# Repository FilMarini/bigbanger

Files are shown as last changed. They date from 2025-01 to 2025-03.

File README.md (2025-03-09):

# BigBanger :boom:

<p align="center">
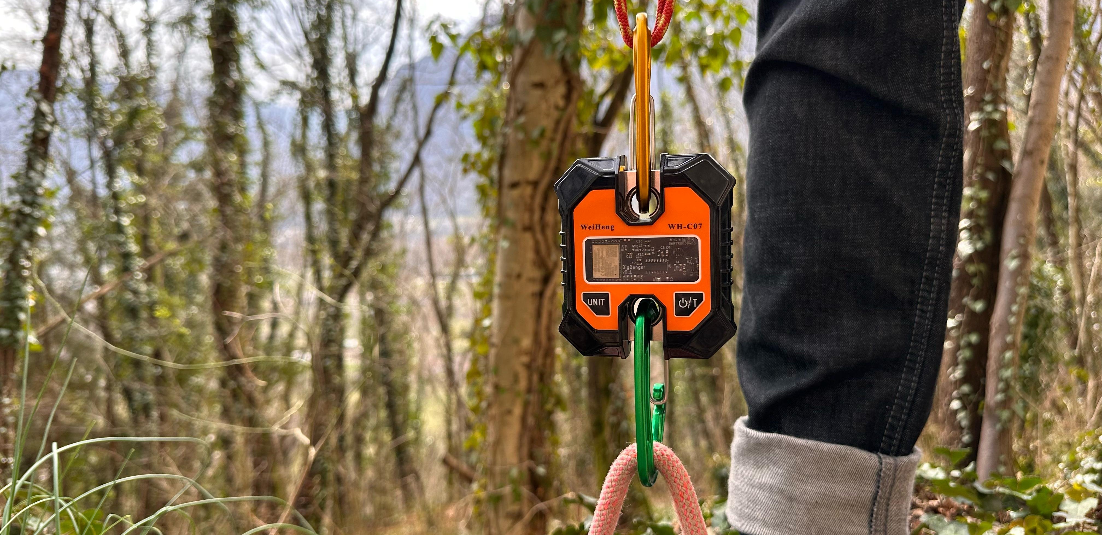
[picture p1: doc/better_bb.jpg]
BigBanger v1.0
  
</p>

BigBanger is an ESP32-based open-source project that combines firmware and hardware to create a Bluetooth-enabled scale, mainly designed for climbing training.

This scale is fully compatible with the [Tindeq Progressor API](https://tindeq.com/progressor_api/), enabling easy integration with apps that support them, including the official Tindeq Progressor app.

The BigBanger board is designed to exploit the housing of cheap scales that you can buy on Amazon/Aliexpress.

Currently, the supported housing are:

* [WeiHeng WH-C07](https://it.aliexpress.com/item/1005004488455473.html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)
* [WeiHeng WH-C100](https://it.aliexpress.com/item/1005007661854154.html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)

This is not the first open-source Tindeq Progressor-like project. The [hangman](https://github.com/kesyog/hangman) is a very similar example. BigBanger was developed from scratch as a personal learning experience.

## Repository structure

* **firmware**: contains the micropython firmware for the ESP32

* **hardware**: contains the Kicad project for the PCB

## Prerequisite

* Python 3.7 or newer

* [esptool](https://docs.espressif.com/projects/esptool/en/latest/esp32/index.html)

* [rshell](https://github.com/dhylands/rshell)

## How-to

1. Build the PCB from the Kicad project. Design is fully compliant with [JLCPCB rules](https://jlcpcb.com/capabilities/pcb-capabilities)

    * The JLCPCB gerbers and assembly files are available in the [release page](https://github.com/FilMarini/bigbanger/releases/tag/v1.1)

    * If you assemble the PCB with JLCPCB, go to step 3

2. Buy the components. [Here](https://www.digikey.it/it/mylists/list/KCSV7UEBPS) is a full Digikey list of parts

3. Get to soldering!

    Battery wiring:
    
    * B+: Red
    * B-: Black

    Load cell wiring:
    
    * E-: Black
    * A-: White
    * A+: Green
    * E+: Red

4. Turn on the BigBanger and connect to PC using the microUSB

    * Device should appear as `/dev/ttyACM*` or `/dev/ttyUSB*`

6. Flash the ESP32 micropython firmware. Instructions and firmware files are [here](https://micropython.org/download/ESP32_GENERIC_C3/)

7. Copy the `.py` files in the 'firmware' folder into the ESP32. Copy the `hx711_gpio.py` file into the ESP32. For this you can use [rshell](https://github.com/dhylands/rshell)

   * Modify the `main.py` file. You need to specify the Bluetooth name for your device (If you want it compatible with the Tindeq Progressor, name must start with `Progressor`) as well as the crane scale used (Supported values are `WH-C07` and `WH-C100`)

    * With [rshell](https://github.com/dhylands/rshell):
    
       ```bash
       git clone --recursive https://github.com/FilMarini/bigbanger.git
       cd bigbanger/firmware
       rshell -p /dev/tty<your device> cp bb_gatt_server.py ble_advertising.py config.py hx711_bb.py utils.py hx711/hx711_gpio.py main.py /pyboard # Probably requires sudo privileges
       ```

9. Start training!

## Calibration

The BigBanger scale comes pre-calibrated, but if for any reason the calibration is lost, you can recalibrate it using the built-in two-point calibration system. This system requires two weight measurements with a 10 kg difference—typically one at zero weight and another at 10 kg.

### How to calibrate

- Turn on the BigBanger scale and ensure it is disconnected from any device.

- Press and hold the Unit button until the LED D5 turns on (this takes a few seconds).

- When the LED turns on, the scale performs the first measurement (normally at zero weight).

- Add 10 kg weight on the scale.

- Press the Unit button again. The LED D5 should turn off.

- The scale is now calibrated and you can now connect to it.

## Acknowledgements

Huge thanks to [Tindeq](https://tindeq.com/product/progressor/) for improving climbing training for all of us with their innovative product and for making their API available to third-party developers, enabling projects like this one. If you find this useful, consider supporting them by getting one of their products—they’re well worth it!

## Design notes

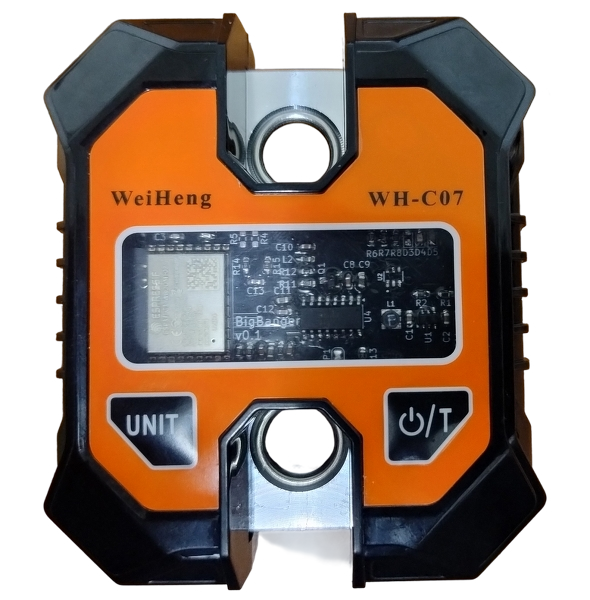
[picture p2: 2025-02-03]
doc/bb.png

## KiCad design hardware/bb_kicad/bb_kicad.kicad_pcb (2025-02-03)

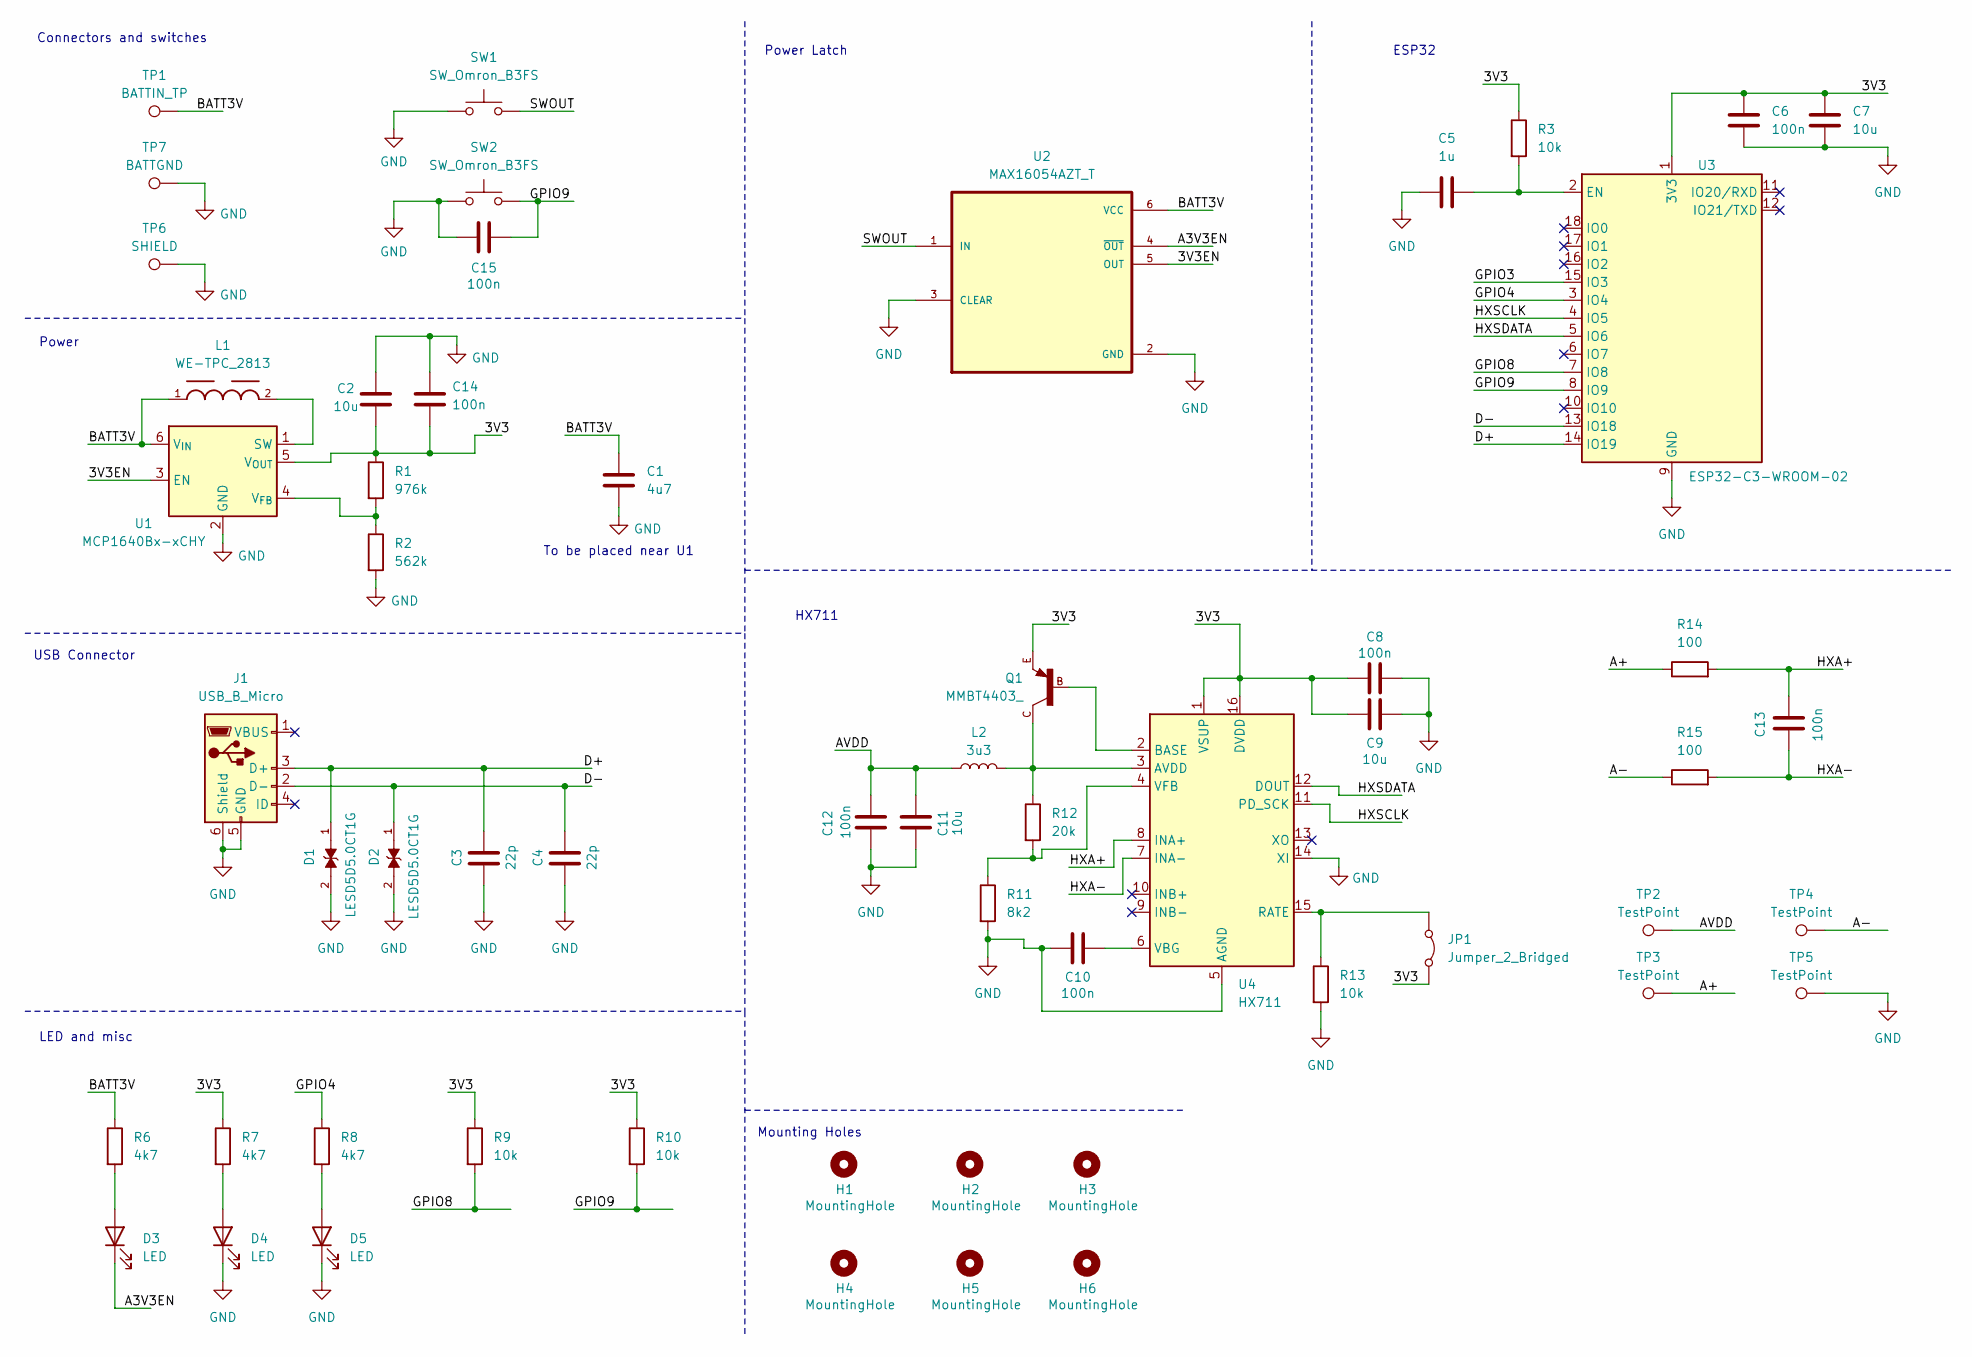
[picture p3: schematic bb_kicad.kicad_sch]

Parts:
C1: 4u7; C_0603_1608Metric_Pad1.08x0.95mm_HandSolder
C2, C7, C9, C11: 10u; C_0603_1608Metric_Pad1.08x0.95mm_HandSolder
C3, C4: 22p; C_0603_1608Metric_Pad1.08x0.95mm_HandSolder
C5: 1u; C_0603_1608Metric_Pad1.08x0.95mm_HandSolder
C6, C8, C10, C12, C13, C14, C15: 100n; C_0603_1608Metric_Pad1.08x0.95mm_HandSolder
D1, D2: LESD5D5.0CT1G; TVS_LESD5D5.0CT1G; PARTREV O
D3, D4, D5: LED; LED_0603_1608Metric_Pad1.05x0.95mm_HandSolder
H1, H2, H3, H4, H5, H6: MountingHole; MountingHole_2.2mm_M2
J1: USB_B_Micro; USB_Micro-B_Amphenol_10118194-0001LF_Horizontal
JP1: Jumper_2_Bridged; SolderJumper-2_P1.3mm_Open_RoundedPad1.0x1.5mm
L1: WE-TPC_2813; DigiKey_Part_Number 732-1089-2-ND
L2: 3u3; L_0603_1608Metric_Pad1.05x0.95mm_HandSolder
Q1: MMBT4403_; SOT23-BEC
R1: 976k; R_0603_1608Metric_Pad0.98x0.95mm_HandSolder
R2: 562k; R_0603_1608Metric_Pad0.98x0.95mm_HandSolder
R3, R9, R10, R13: 10k; R_0603_1608Metric_Pad0.98x0.95mm_HandSolder
R6, R7, R8: 4k7; R_0603_1608Metric_Pad0.98x0.95mm_HandSolder
R11: 8k2; R_0603_1608Metric_Pad0.98x0.95mm_HandSolder
R12: 20k; R_0603_1608Metric_Pad0.98x0.95mm_HandSolder
R14, R15: 100; R_0603_1608Metric_Pad0.98x0.95mm_HandSolder
SW1, SW2: SW_Omron_B3FS; SW_SPST_Omron_B3FS-101xP
TP1: BATTIN_TP; TestPoint_Pad_2.0x2.0mm
TP2, TP3, TP4, TP5: TestPoint; TestPoint_Pad_2.0x2.0mm
TP6: SHIELD; TestPoint_Pad_2.0x2.0mm
TP7: BATTGND; TestPoint_Pad_2.0x2.0mm
U1: MCP1640Bx-xCHY; SOT-23-6
U2: MAX16054AZT_T; SOT95P275X110-6N
U3: ESP32-C3-WROOM-02
U4: HX711; SOP-16_3.9x9.9mm_P1.27mm

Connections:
/3V3: C2.2, C6.2, C7.2, C8.1, C9.1, C14.2, JP1.2 (B), Q1.E, R1.1, R3.1, R7.1, R9.1, R10.1, U1.5 (V_{OUT}), U3.1 (3V3), U4.1 (VSUP), U4.16 (DVDD)
/3V3EN: U1.3 (EN), U2.5 (OUT)
/A3V3EN: D3.1 (K), U2.4 (~OUT)
/A+: R14.1, TP3.1
/A-: R15.1, TP4.1
/AVDD: C11.2, C12.2, L2.1, TP2.1
/BATT3V: C1.1, L1.1, R6.1, TP1.1, U1.6 (V_{IN}), U2.6 (VCC)
/D+: C3.1, D1.1, J1.3 (D+), U3.14 (IO19)
/D-: C4.1, D2.1, J1.2 (D-), U3.13 (IO18)
/GPIO3: U3.15 (IO3)
/GPIO4: R8.1, U3.3 (IO4)
/GPIO8: R9.2, U3.7 (IO8)
/GPIO9: C15.2, R10.2, SW2.2, U3.8 (IO9)
/HXA+: C13.2, R14.2, U4.8 (INA+)
/HXA-: C13.1, R15.2, U4.7 (INA-)
/HXSCLK: U3.4 (IO5), U4.11 (PD_SCK)
/HXSDATA: U3.5 (IO6), U4.12 (DOUT)
/SWOUT: SW1.2, U2.1 (IN)
GND: C1.2, C2.1, C3.2, C4.2, C5.1, C6.1, C7.1, C8.2, C9.2, C10.1, C11.1, C12.1, C14.1, C15.1, D1.2, D2.2, D4.1 (K), D5.1 (K), J1.5 (GND), J1.6 (Shield), R2.2, R11.2, R13.2, SW1.1, SW2.1, TP5.1, TP6.1, TP7.1, U1.2 (GND), U2.2 (GND), U2.3 (CLEAR), U3.9 (GND), U3.19 (GND), U4.5 (AGND), U4.14 (XI)
unnamed: D3.2 (A), R6.2
unnamed: D4.2 (A), R7.2
unnamed: D5.2 (A), R8.2
unnamed: JP1.1 (A), R13.1, U4.15 (RATE)
unnamed: L1.2, U1.1 (SW)
unnamed: R1.2, R2.1, U1.4 (V_{FB})
unnamed: C5.2, R3.2, U3.2 (EN)
unnamed: L2.2, Q1.C, R12.1, U4.3 (AVDD)
unnamed: Q1.B, U4.2 (BASE)
unnamed: C10.2, U4.6 (VBG)
unnamed: R11.1, R12.2, U4.4 (VFB)

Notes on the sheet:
LED and misc
USB Connector
ESP32
Power
Mounting Holes
Connectors and switches
Power Latch
HX711
To be placed near U1

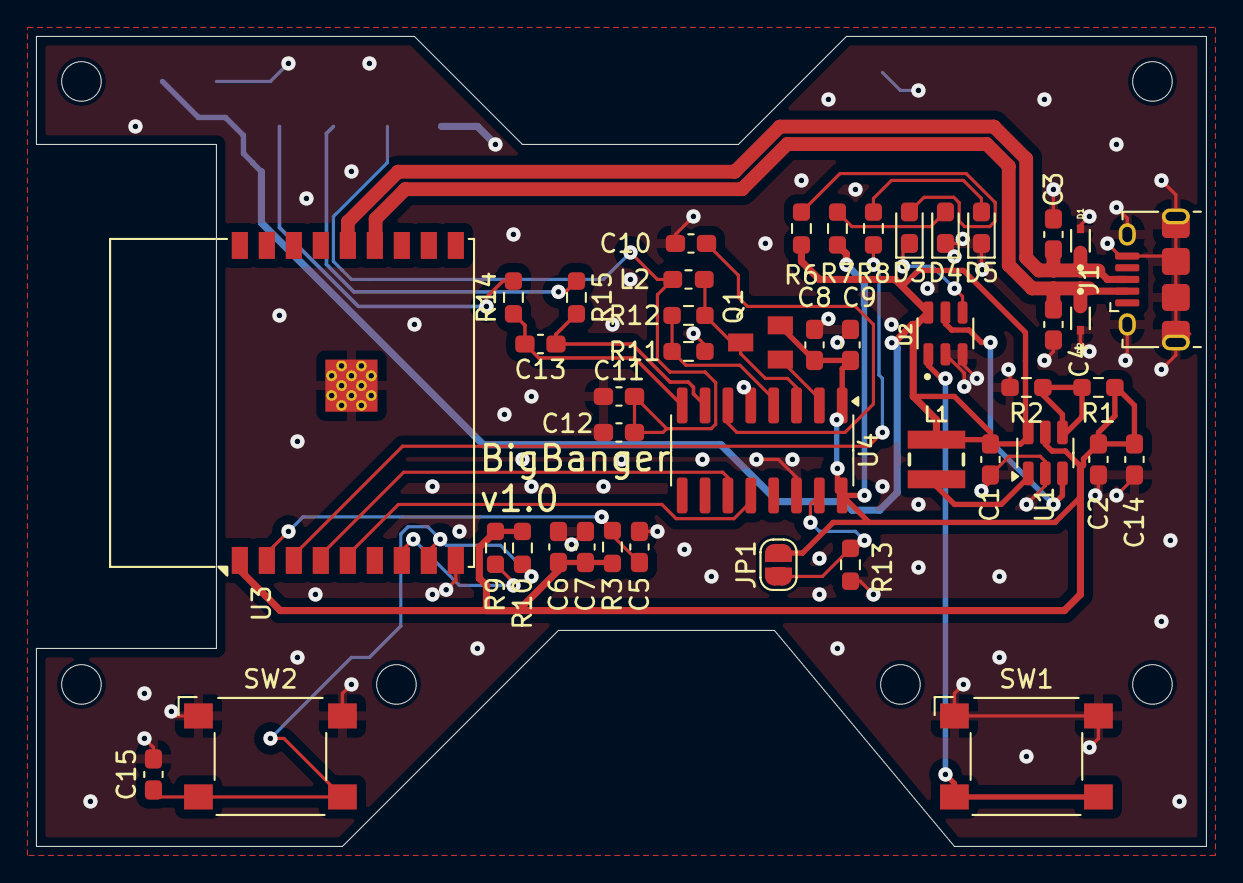
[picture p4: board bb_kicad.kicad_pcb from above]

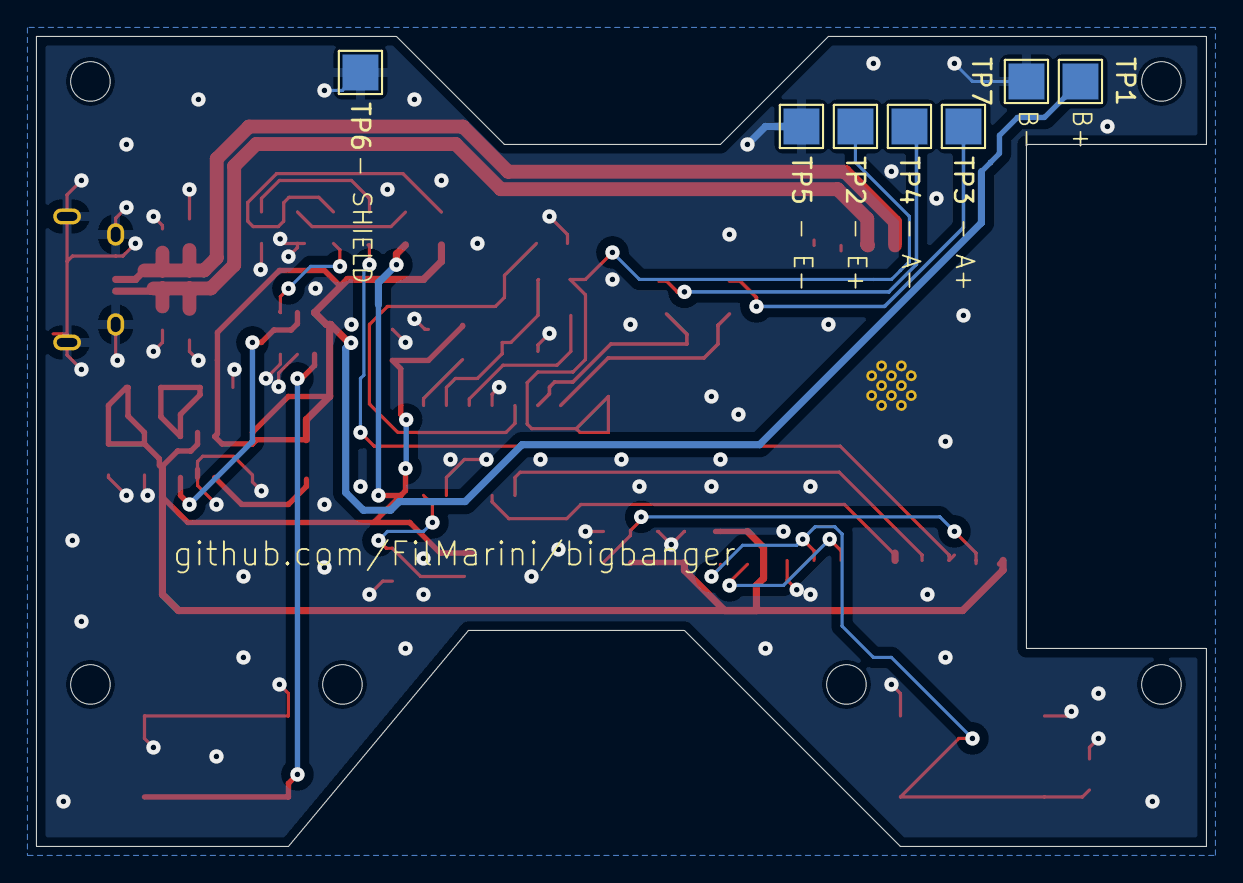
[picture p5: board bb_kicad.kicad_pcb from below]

Board: 2 copper layers, 65.0 x 45.0 mm, 57 parts (7 on the bottom side), 29 nets.

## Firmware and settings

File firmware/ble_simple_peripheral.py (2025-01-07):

"""
Author: Filippo Marini
Email: marinifil@gmail.com
Repository: https://github.com/FilMarini/bigbanger
License: Apache License, Version 2.0
Original Source: https://github.com/micropython/micropython

Notes:
This file is part of an open-source project. Feel free to contribute or report issues on the project's repository.

"""

import bluetooth
import random
import struct
import time
from ble_advertising import advertising_payload
import asyncio

from micropython import const

_IRQ_CENTRAL_CONNECT = const(1)
_IRQ_CENTRAL_DISCONNECT = const(2)
_IRQ_GATTS_WRITE = const(3)

_FLAG_READ = const(0x0002)
_FLAG_WRITE_NO_RESPONSE = const(0x0004)
_FLAG_WRITE = const(0x0008)
_FLAG_NOTIFY = const(0x0010)

_PROGRESSOR_SERVICE_UUID = bluetooth.UUID("7e4e1701-1ea6-40c9-9dcc-13d34ffead57")
_PROGRESSOR_DATA_CHAR = (
    bluetooth.UUID("7e4e1702-1ea6-40c9-9dcc-13d34ffead57"),
    _FLAG_READ | _FLAG_NOTIFY,
)
_PROGRESSOR_CONTROL_POINT = (
    bluetooth.UUID("7e4e1703-1ea6-40c9-9dcc-13d34ffead57"),
    _FLAG_WRITE | _FLAG_WRITE_NO_RESPONSE,
)
_PROGRESSOR_SERVICE = (
    _PROGRESSOR_SERVICE_UUID,
    (_PROGRESSOR_DATA_CHAR, _PROGRESSOR_CONTROL_POINT),
)

""" Progressor Commands """
CMD_TARE_SCALE = 100
CMD_START_WEIGHT_MEAS = 101
CMD_STOP_WEIGHT_MEAS = 102
CMD_START_PEAK_RFD_MEAS = 103
CMD_START_PEAK_RFD_MEAS_SERIES = 104
CMD_ADD_CALIBRATION_POINT = 105
CMD_SAVE_CALIBRATION = 106
CMD_GET_APP_VERSION = 107
CMD_GET_ERROR_INFORMATION = 108
CMD_CLR_ERROR_INFORMATION = 109
CMD_ENTER_SLEEP = 110
CMD_GET_BATTERY_VOLTAGE = 111
CMD_GET_DEVICE_ID = 112

""" Progressor response codes """
RES_CMD_RESPONSE = 0
RES_WEIGHT_MEAS = 1
RES_RFD_PEAK = 2
RES_RFD_PEAK_SERIES = 3
RES_LOW_PWR_WARNING = 4

"""Progressor variables"""
PROG_VER = "1.2.3.4"
BATTERY_VOLTAGE = 3000 #mV
DEVICE_ID = 43
CRASH_MSG = "No crash"
#WEIGHTS = [0, 0, 0, 0.2, 0.5, 0.9, 1.5, 2, 3, 5, 6, 7, 8, 9, 9, 9, 9, 9, 9, 9, 9, 8, 7, 6, 5, 4, 3, 2, 1, 0, 0, 0, 0, 0, 0, 0, 0, 0, 0, 0, 0, 0, 0, 0, 1, 2, 3, 4, 5, 6, 7, 8, 9, 9, 9, 9, 9, 9, 9, 9, 9, 9, 9, 9, 9, 9, 9, 9, 9, 9, 9, 9, 8, 7, 6, 5, 4, 3, 2, 1, 0]
WEIGHTS = [1.1, 1.0, 1.2, 1.0, 1.0, 1.0, 1.1, 1.1, 1.2, 1.0, 1.1]

def byte_length(n):
    if n == 0:
        return 1  # Even 0 requires at least 1 byte
    bytes_count = 0
    while n:
        n >>= 8  # Shift 8 bits (1 byte) at a time
        bytes_count += 1
    return bytes_count

class BLESimplePeripheral:
    def __init__(self, ble, name = "Progressor_BB"):
        self._ble = ble
        self._ble.active(True)
        self._ble.irq(self._irq)
        ((self._handle_data, self._handle_control),) = self._ble.gatts_register_services((_PROGRESSOR_SERVICE,))
        self._connections = set()
        self._write_callback = None
        self._payload = advertising_payload(services=[_PROGRESSOR_SERVICE_UUID])
        self._payload_resp = advertising_payload(name = name)
        self._sending_data = False
        self._start_time_us = None
        self.tare_scale = False
        self.weight_tare = 0
        self._advertise()

    def _irq(self, event, data):
        # Track connections so we can send notifications.
        if event == _IRQ_CENTRAL_CONNECT:
            conn_handle, _, _ = data
            print("New connection", conn_handle)
            self._connections.add(conn_handle)
        elif event == _IRQ_CENTRAL_DISCONNECT:
            conn_handle, _, _ = data
            print("Disconnected", conn_handle)
            self._connections.remove(conn_handle)
            # Start advertising again to allow a new connection. Alsways connects when there is an available node.
            self._sending_data = False
            self._advertise()
        elif event == _IRQ_GATTS_WRITE:
            conn_handle, value_handle = data
            value = self._ble.gatts_read(value_handle)
            if value_handle == self._handle_control:
                self.process_command(value)

    def process_command(self, value):
        value_int = int.from_bytes(value, "big")
        print(f'Command {value_int} received!')
        for conn_handle in self._connections:
            if value_int == CMD_GET_APP_VERSION:
                size = len(PROG_VER)
                byte_array = bytearray([RES_CMD_RESPONSE, size]) + bytearray(PROG_VER.encode('utf-8'))
                self._ble.gatts_notify(conn_handle, self._handle_data, byte_array)
            elif value_int == CMD_GET_BATTERY_VOLTAGE:
                pre_size = byte_length(BATTERY_VOLTAGE)
                size = pre_size if pre_size > 4 else 4
                byte_array = bytearray([RES_CMD_RESPONSE, size]) + bytearray(BATTERY_VOLTAGE.to_bytes(size, "little"))
                self._ble.gatts_notify(conn_handle, self._handle_data, byte_array)
            elif value_int == CMD_GET_DEVICE_ID:
                pre_size = byte_length(DEVICE_ID)
                size = pre_size if pre_size > 8 else 8
                byte_array = bytearray([RES_CMD_RESPONSE, size]) + bytearray(DEVICE_ID.to_bytes(size, "little"))
                self._ble.gatts_notify(conn_handle, self._handle_data, byte_array)
            elif value_int == CMD_GET_ERROR_INFORMATION:
                size = len(CRASH_MSG)
                byte_array = bytearray([RES_CMD_RESPONSE, size]) + bytearray(CRASH_MSG.encode('utf-8'))
                self._ble.gatts_notify(conn_handle, self._handle_data, byte_array)
            elif value_int == CMD_START_WEIGHT_MEAS:
                self._sending_data = True
                self._start_time_us = time.ticks_us()  # Record the start time in microseconds
            elif value_int == CMD_STOP_WEIGHT_MEAS:
                self._sending_data = False
                self._start_time_us = None
            elif value_int == CMD_TARE_SCALE:
                self.tare_scale = True

    def is_connected(self):
        return len(self._connections) > 0

    def _advertise(self, interval_us=500000):
        print("Starting advertising")
        self._ble.gap_advertise(interval_us, adv_data=self._payload, resp_data=self._payload_resp)

    async def send_data_loop(self):
        i = 0
        while True:
            if self._sending_data and self.is_connected():
                # Raw values to send
                elapsed_us = time.ticks_diff(time.ticks_us(), self._start_time_us)  # Calculate elapsed microseconds
                weight = WEIGHTS[i%len(WEIGHTS)] - self.weight_tare
                if self.tare_scale:
                    self.weight_tare = weight
                    self.tare_scale = False
                # Values to send
                weight_data = bytearray(struct.pack('f', weight))
                elapsed_us_data = bytearray(elapsed_us.to_bytes(4, "little"))
                # Create packet
                size = 8
                byte_array = bytearray([RES_WEIGHT_MEAS, size]) + weight_data + elapsed_us_data
                for conn_handle in self._connections:
                    data = f"Data {i}, Elapsed: {elapsed_us} µs"
                    print(f"Sending: {data}")
                    self._ble.gatts_notify(conn_handle, self._handle_data, byte_array)
                    i += 1
            await asyncio.sleep(0.2)  # Adjust the interval as needed



async def demo():
    ble = bluetooth.BLE()
    p = BLESimplePeripheral(ble)

    # Start the data sending loop
    asyncio.create_task(p.send_data_loop())

    # Keep the main loop running
    while True:
        await asyncio.sleep(1)


if __name__ == "__main__":
    asyncio.run(demo())

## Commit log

2025-01-07 add device id
2025-01-07 first hardware commit
    [bb_v0.1.kicad_pcb, bb_v0.1.kicad_sch]
2025-01-07 first commit of full schematic
    [bb_v0.1.kicad_sch]
2025-01-07 fixed schematic
    [bb_v0.1.kicad_sch]
2025-01-08 first complete layout
    [bb_v0.1.kicad_pcb, bb_v0.1.kicad_sch]
2025-01-08 added button
    [bb_v0.1.kicad_pcb, bb_v0.1.kicad_sch]
2025-01-08 first version complete layout
    [bb_v0.1.kicad_pcb]
2025-01-09 moved kicad project location to show supported housings
    [bb_v0.1.kicad_pcb, bb_v0.1.kicad_sch]
2025-01-09 checked measures
    [bb_v0.1.kicad_pcb]
2025-01-09 first design submitted
    [bb_v0.1.kicad_pcb]
2025-01-24 changed kicad project location
    [bb_v0.1.kicad_pcb, bb_v0.1.kicad_sch]
2025-01-25 fixed oversights after first iteration
    [bb_v0.1.kicad_pcb, bb_v0.1.kicad_sch]
2025-02-03 changed project name and version
    [bb_kicad.kicad_pcb, bb_kicad.kicad_sch]
2025-02-18 Calibration mode (#3)
    Adding calibration mode to the BigBanger fw
